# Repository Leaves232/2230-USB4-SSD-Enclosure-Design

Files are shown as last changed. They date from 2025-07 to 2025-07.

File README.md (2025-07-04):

## 2230 USB4 SSD Enclosure Design

The purpose of this project is to verify the feasibility of a 40Gbps SSD enclosure solution in limited volume. 

This design has gone through several iterations. The current open source design file includes support for active cooling and has considerable compatibility.

The finished product of the open-source file is shown in the picture. The design of the adaptive shell is still in the planning stage.

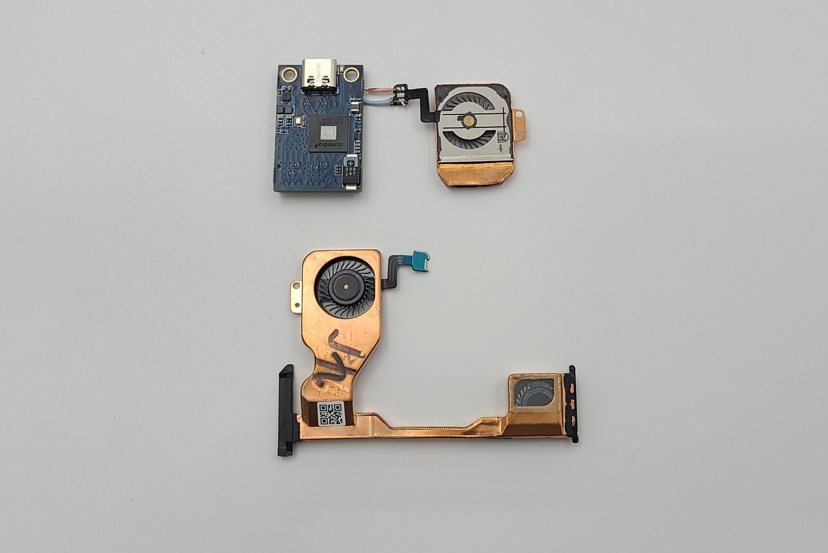
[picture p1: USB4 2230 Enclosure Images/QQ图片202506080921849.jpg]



### Function Availability

Speed tests using a P44 Pro 2T also confirmed that the design is fully functional

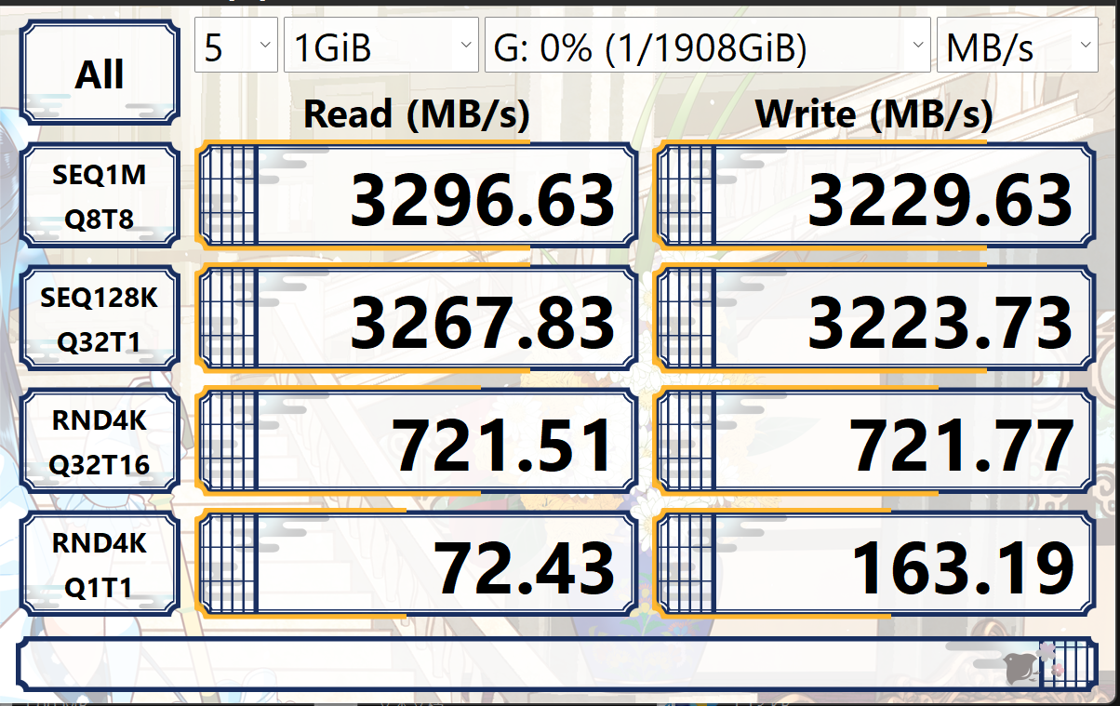
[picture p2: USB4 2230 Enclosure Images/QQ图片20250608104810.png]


This design has been checked to widely compatible with SSD.

It should be noted that due to limitation of the 3.3V Buck, it cannot meet the power consumption requirements of 4T SSDs. **Please use it with SSDs within 2T**.

## HOW TO USE FILES

**ASM2464PD DEMO Board B2 [Altium Designer]** folder contains the design source files developed using Altium Designer. You can make secondary modifications based on these files. The others are files used for finished product manufacturing.

### PCB Manufacturing

**Fabrication Files For DEMO Board B2** contains complete Gerber and drilling files for PCB production, which can be compressed and uploaded directly to board manufacturers such as JLC and Huaqiu for production. 

The PCB in Image Sets was made by Huaqiu PCB, and the stackup used was **04161H02-1080**. If you plan to produce the same PCB, please sent it directly to Huaqiu according to the corresponding parameters. 

If you plan to produce via other manufacturers, please emphasize to the production staff that the differential line impedance of the top and bottom layers should be controlled to about 85ohm according to the impedance requirements in the folder.

| 参数/Configuration | 下单参数/Parameter|
| --- | --- |
|板材类型/Board Material Type | FR-4 |
| 板子层数/Number of Layers | 4 |
| 板子厚度/Board Thickness | 1.6 |
| 最小线宽线距/Minimum Trace Width/Space | 3.5 / 3.5 mil |
| 最小过孔/Minimum Via Size | 0.20 mm |
| BGA | 无/None |
| 半孔/Castellated Hole | 无需/Not required |
| 包边/Edge Bonding / Board Edge Plating | 无需/Not required |
| 盲埋孔/Buried Via  | 无/None |
| 阻抗/Impedance Control  | 有/Require |
| 叠层结构/Layer Stack-up Structure | 04161H02-1080 |
| 焊盘喷镀/Surface Finish | 沉金(1u)/ENIG (1μm Au) |
| 外层铜厚/Outer Layer Copper Weight | 1oz |
| 内层铜厚/Inner Layer Copper Weight | 0.5oz |
| 阻焊颜色/Solder Mask Color | 蓝色/Blue |
| 字符颜色/Legend Color | 白色/White |
| 阻焊覆盖/Solder Mask Coverage  | 过孔盖油/Via Tent |
| 盘中孔/Via-in-Pad  | 无/None |
| 沉金厚度/Electroless Nickel Immersion Gold  | 1 μ″ |
| 板材品牌/Laminate Brand | 建滔 |
| TG值/Tg Value (Glass Transition Temperature) | TG150 |

### SMT Manufacturing

**Bill of Materials for B2 Sample.xlsx** could be used to prepare components for PCBA manufacturing.

**Pick Place for ASM2464PD - B2 Sample.csv** is the location coordinates of each component, which is used to provide parameters for the SMT placement machine.

 When purchasing materials on your own, Please pay attention to packaging, capacitor withstand voltage, and price issues, or refer to the material selection list I used at Huaqiu **PCBA Project - BOM Quotation for 2230 USB4 Enclosure**

Please refer to the picture for SMT finished product effect

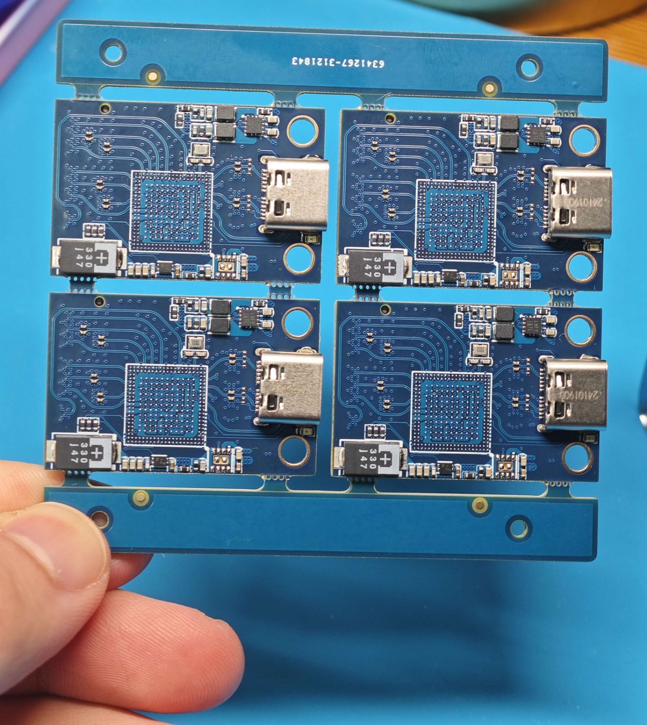
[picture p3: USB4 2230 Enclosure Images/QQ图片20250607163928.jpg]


### Firmware Write

It is recommended to connect the completed ASM2464PD board to the USB port of computer when you try to write the firmware.

Download **ASM2464PD_FW_250123_85_00_00.zip** and unzip it to a separate folder

Unzip **20231221_ASM246xMPTool_v1.0.4.1** and run **ASM246xMPTool.exe**

Please follow the prompts below

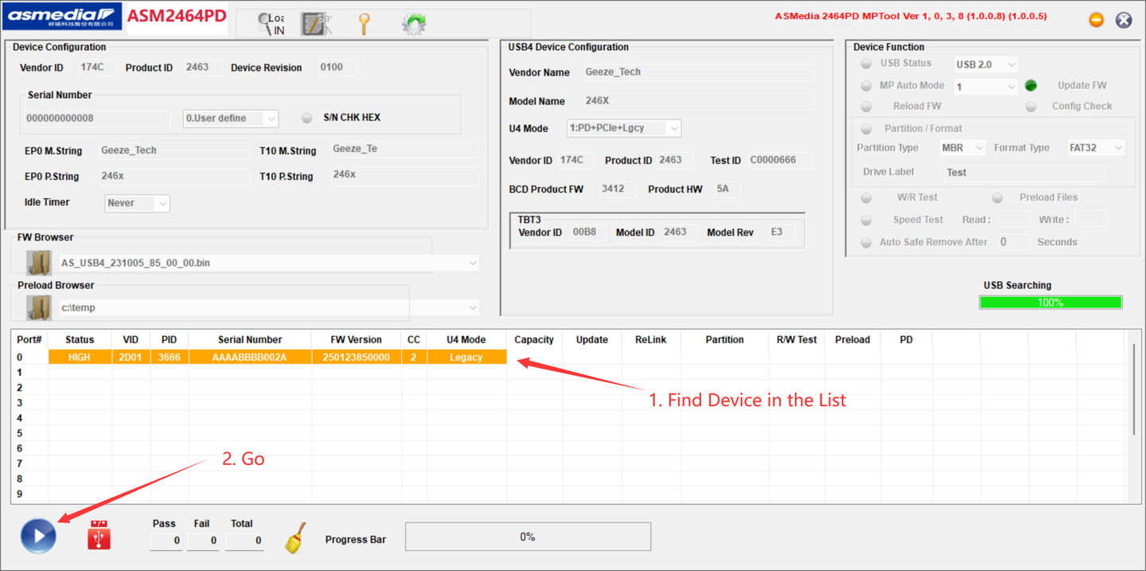
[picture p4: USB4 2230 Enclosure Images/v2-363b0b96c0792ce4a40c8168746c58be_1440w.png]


For other tips, please refer to the ASM2464PD_PDX mptool instructions in the folder

### Cooling Fan

Caution: ASM2464PD finished product will inevitably overheat and disconnect without heat dissipation.

The cooling fan in the demo is obtained by cutting the cooling module of Lenovo Legion Pro2.

You can connect it with flying wires, apply silicone grease and press it directly on the 2464 main controller.

### Congratulations, after completing the above steps you have a fully functional USB4 2230 SSD enclosure !

## License

The design is jointly completed by **@Leaves** and **@七上八下**. 

This project is open sourced under the MIT protocol.

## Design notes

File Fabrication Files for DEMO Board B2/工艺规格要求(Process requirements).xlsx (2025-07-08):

板材类型/Material Type | FR-4
板子层数/Layer Count | 4
板子厚度/Board Thickness | 1.6mm
外层铜厚/Outer Layer Copper Weight | 1oz
内层铜厚/Inner Layer Copper Weight | 1oz
阻抗/Impedance Control | 50/85
阻抗要求/Impedance Requirements
层 |  | 阻抗类型/Impedance type | 阻抗/Impedance | 线宽/Trace Width | 间距/Clearance
Layer | 1 | 差分/Differential Pair | 85Ohm | 4.36mil | 4mil
 |  | 单端/Single-ended | 50Ohm | 4.5mil | /
 | 2-3 | 差分/Differential Pair | 85Ohm | 3.69mil | 4mil
 |  | 单端/Single-ended | 50Ohm | 3.92mil | /
 | 4 | 差分/Differential Pair | 85Ohm | 4.36mil | 4mil
 |  | 单端/Single-ended | 50Ohm | 4.5mil | /

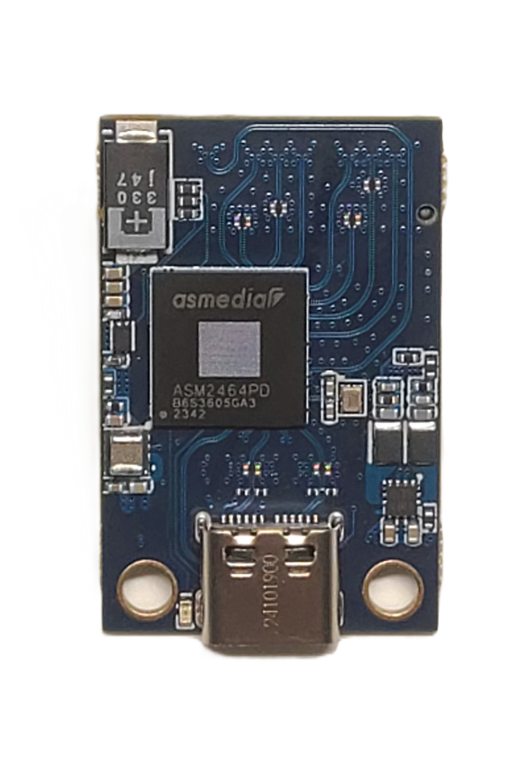
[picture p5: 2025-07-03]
USB4 2230 Enclosure Images/QQ图片20250607053230.png

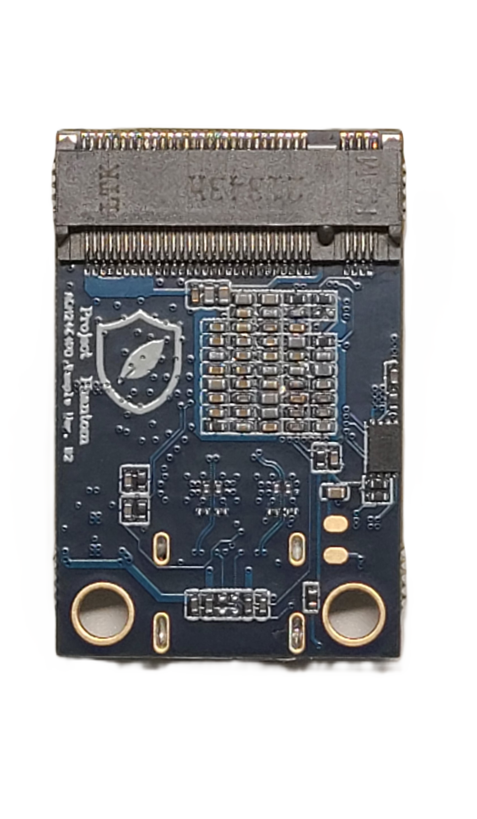
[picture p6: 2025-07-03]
USB4 2230 Enclosure Images/QQ图片20250607053236.png

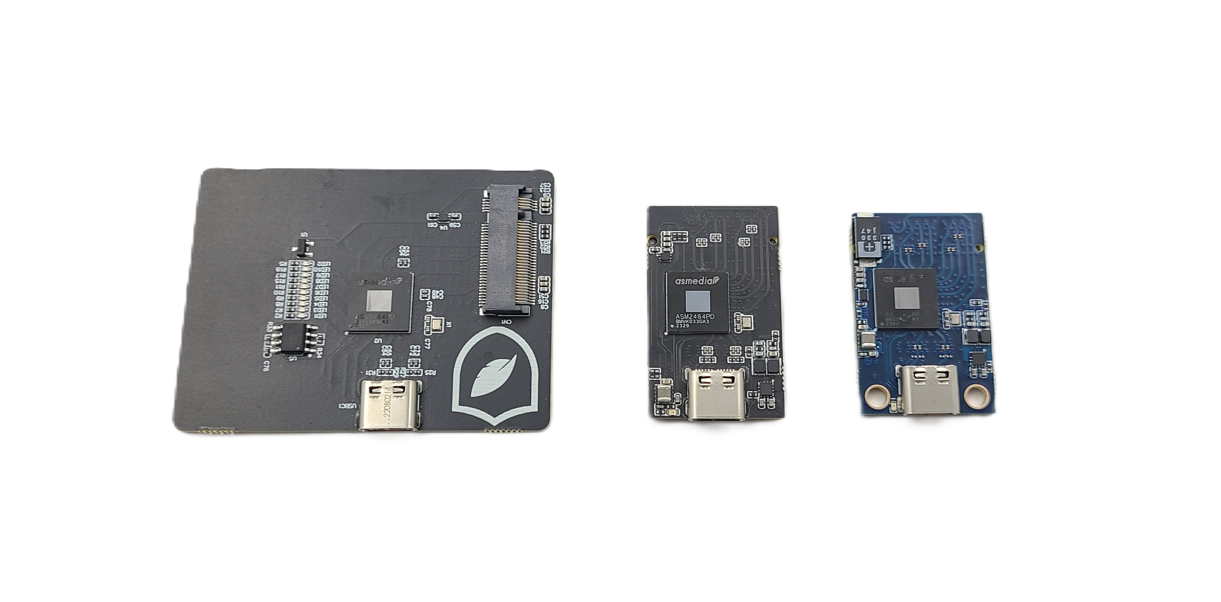
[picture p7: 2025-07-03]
USB4 2230 Enclosure Images/QQ图片2025060q8093125.jpg

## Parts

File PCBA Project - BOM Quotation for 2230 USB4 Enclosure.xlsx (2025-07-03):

PCBA Project - BOM Quotation
 |  |  |  |  |  | 65.71 |  |  | 报价有效期至：2025-05-12 06:30:00
 |  |  |  |  |  | “华秋商城”BOM匹配数据
序号/NO. | 型号/Part Number | 规格参数/Specifications | 封装//Package | 单机用量Usage per Unit | 位号/Reference Designator | 型号/Part Number | 描述/Description | 品牌/Manufacturer Brand | 含税单价(¥)/Unit Price (CNY, Tax incl.)
1 |  | 22uF | C0402 | 3 | C7, C102,C108 | GRM155R60J226ME11D | 贴片电容（MLCC） 0402 22µF ±20% 6.3V X5R | Samsung | 0.22275
2 |  | 10uF | C0402 | 15 | C4, C8, C13, C16, C20, C23, C40, C43, C46, C51, C57, C103, C104, C109,C100 | CL05A106MQ5NUNC | 贴片电容（MLCC） 0402 10µF ±20% 6.3V X5R | Samsung | 0.02281
3 |  | 2.2uf | C0402 | 26 | C1, C3, C6, C10, C12, C15, C17, C19, C22, C24, C26, C28, C29, C30, C32, C33, C35, C36, C37, C38, C39, C41, C42, C44, C45, C47 | CL05A225KP5NSNC | 贴片电容（MLCC） 0402 2.2µF ±10% 10V X5R | Samsung | 0.01346
4 |  | 100nF | C0402 | 16 | C2, C5, C9, C11, C14, C18, C21, C25, C27, C31, C61, C66, C67, C70, C71, C76 | 0402F104M500NT | 贴片电容（MLCC） 0402 100nF ±20% 50V Y5V | FH | 0.00481
5 |  | 1uF | C0402 | 1 | C34 | 0402X105K6R3NT | 贴片电容（MLCC） 0402 1µF ±10% 6.3V X5R | FH | 0.00766
6 |  | 220nF | C0201 | 12 | C48, C49, C50, C52, C53, C54, C55, C56, C64, C65, C74, C75 | GRM033R60J224ME15D | 贴片电容（MLCC） 0201 220nF ±20% 6.3V X5R | Murata | 0.00917
7 |  | 20pF | C0402 | 1 | C59 | CC0402JRNPO9BN200 | 贴片电容（MLCC） 0402 20pF ±5% 50V C0G(NP0) | Yageo | 0.00456
8 |  | 330nF | C0201 | 4 | C62, C63, C72, C73 | GRM033R60J334ME90D | 贴片电容（MLCC） 0201 330nF ±20% 6.3V X5R | Murata | 0.05114
9 |  | 220pF | C0402 | 2 | C68, C69 | 0402B221K500NT | 贴片电容（MLCC） 0402 220pF ±10% 50V X7R | FH | 0.00433
10 |  | 30pF | C0402 | 2 | C77, C78 | 0402CG300J500NT | 贴片电容（MLCC） 0402 30pF ±5% 50V C0G(NP0) | FH | 0.00454
11 |  | 4.7pf | C0402 | 1 | C101 | 0402CG4R7B500NT | 贴片电容（MLCC） 0402 4.7pF ±0.1pF 50V | FH | 0.00744
12 |  | 6.8pf | C0402 | 1 | C105 | 0402CG6R8C500NT | 贴片电容（MLCC） 0402 6.8pF ±0.25pF 50V C0G(NP0) | FH | 0.00420
13 |  | 33u | C0402 | 1 | C106 | GRM155R60J226ME11D | GRM158R61A226ME15D | Murata | 0.67700
14 |  | 3.3nf | C0402 | 1 | C107 | 0402B332K500NT | 贴片电容（MLCC） 0402 3.3nF ±10% 50V X7R | FH | 0.00382
15 |  | 330uF | CAP-SMD_L7.3-W4.3-R-RD | 1 | CE1 | 6TPE330MAP | 钽聚合物电容器 D7343-18 330µF ±20% 6.3V 7.30 x 4.30mm 25mΩ | Panasonic | 2.37008
16 | M.2-MKEY CONNECTOR | M.2-MKEY CONNECTOR | CONN-SMD_APCI0113-P001A | 1 | CN1 | NASM0-S6701-TPH4 | M.2 M KEY H3.0 | ARGOSY | 1.41750
17 |  | HDR1x1 | Header | 2 | J17, J18 | NC
18 |  | 1uh | IND-SMD_L2.0-W1.6-B | 2 | L5, L6 | FTC201610S1R0MBCA | 2.0*1.6*1.0 (201610) 电感值:1.0µH 精度:±20% 饱和电流（isat）：4.6A 温升电流（irms）：4.5A 直流电阻(DCR)：35mΩ | cjiang | 0.19611
19 | 19-217/R6C-AL1M2VY/3T | 19-217/R6C-AL1M2VY/3T | LED0402-RD | 1 | LED1 | 19-217/R6C-AL1M2VY/6T | 发光二极管/LED 0603 红灯 正贴 | Everlight | 0.07979
20 |  | 4.7K 1% | R0402 | 5 | R1, R2, R3, R33, R34 | 0402WGF4701TCE | 贴片电阻 0402 4.7KΩ ±1% 1/16W ±100ppm/℃ | Uniohm | 0.00219
21 |  | 12.1K 1% | R0402 | 1 | R4 | 0402WGF1212TCE | 贴片电阻 0402 12.1KΩ ±1% 1/16W ±100ppm/℃ | Uniohm | 0.00212
22 |  | 100K 1% | R0402 | 3 | R6, R104, R106 | 0402WGF1003TCE | 贴片电阻 0402 100KΩ ±1% 1/16W ±100ppm/℃ | Uniohm | 0.00200
23 |  | 0 | R0402 | 2 | R12, R13 | 0402WGF0000TCE | 贴片电阻 0402 0Ω ±1% 1/16W | Uniohm | 0.00198
24 |  | 2M /NC | R0402 | 2 | R14, R16 | NC
25 |  | 100K /NC | R0402 | 1 | R19 | NC
26 |  | 1K 1% | R0402 | 1 | R20 | 0402WGF1001TCE | 贴片电阻 0402 1KΩ ±1% 1/16W ±100ppm/℃ | Uniohm | 0.00222
27 |  | 10K 1% | R0402 | 5 | R21, R22, R23, R103, R110 | 0402WGF1002TCE | 贴片电阻 0402 10KΩ ±1% 1/16W ±100ppm/℃ | Uniohm | 0.00216
28 |  | 220K 1% | R0201 | 8 | R24, R25, R26, R27, R28, R29, R30, R31 | 0201WMF2203TEE | 贴片电阻 0201 220KΩ ±1% 1/20W ±200ppm/℃ | Uniohm | 0.00446
29 |  | 140K 1% | R0402 | 1 | R105 | RC0402FR-07140KL | 贴片电阻 0402 140KΩ ±1% 1/16W ±100ppm/℃ | Yageo | 0.00279
30 |  | 261K 1% | R0402 | 1 | R107 | 0402WGF2613TCE | 贴片电阻 0402 261KΩ ±1% 1/16W ±100ppm/℃ | UniOhm | 0.00216
31 |  | 475K 1% | R0402 | 1 | R108 | RC0402FR-07475KL | 贴片电阻 0402 475KΩ ±1% 1/16W ±100ppm/℃ | Yageo | 0.00446
32 |  | 150K 1% | R0402 | 1 | R109 | 0402WGF1503TCE | 贴片电阻 0402 150KΩ ±1% 1/16W ±100ppm/℃ | Uniohm | 0.00213
33 | tpc60t_68 | tpc60t_68 | tpc60t_68 | 2 | TP1, TP2
34 | LTC3315AEV#TRPBF | LTC3315AEV#TRPBF | LQFN-12_L2.0-W2.0-P0.50-TL-EP0.7 | 1 | U01 | LTC3315AEV#TRPBF | IC REG BUCK 6A STEP-DOWN | ADI | 16.64280
35 | ASM2464PD | ASM2464PD | BGA273C46P21X21_1000X1000X98 | 1 | U2
36 | TPS82130SILR | TPS82130SILR | USIP-8_L3.0-W2.8-P0.65-TL-EP | 1 | U02 | TPS82130SILR | 非隔离 PoL 模块 直流转换器 1 输出 0.9 ~ 5V 3A 3V - 17V 输入 μSIP8_3X2.8MM | TI | 22.94600
37 | SIP32408DNP-T1-GE4 | SIP32408DNP-T1-GE4 | SIP32408DNP-T1-GE4 | 1 | U4 | SIP32408DNP-T1-GE4 | IC PWR SWITCH N-CHAN 1:1 4TDFN | Vishay | 4.50360
38 | ZD25WQ16CEIGR | ZD25WQ16CEIGR | USON-8_L3.0-W2.0-P0.50-BL-EP | 1 | U31 | ZD25WQ16CEIGR |  | Zetta(澜智) | 1.02600
39 | 105450-0101 | 105450-0101 | USB-C-SMD_TYPE-C-USB-18 | 1 | USBC1 | 105450-0101 |  | Molex | 6.32500
40 |  | 25MHz | CRYSTAL-SMD_4P-L1.6-W1.2-BL | 1 | X1 | X322525MSB4SI | 无源晶振 25MHz 50Ω 20pF ±10ppm -40℃~+85℃ SMD3225_4P | YXC | 0.29520

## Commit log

2025-06-11 Altium raw files for 2230 ASM2464PD Board
    Prototype design completed with Altium Designer, which can be modified, previewed, etc. in Altium software
    [ASM2464PD.PcbLib, ASM2464PD.PrjPcb, ASM2464PD.SchDoc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]
2025-06-11 B2 Sample Fabrication Documents
    Files directly for B2 sample PCB manufacture
    [ASM2464PD - B2 Sample.GBL, ASM2464PD - B2 Sample.GBO, ASM2464PD - B2 Sample.GBP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]
2025-06-11 Bill of Materials For 2230 USB4 SSD Enclosure
    Contains a list of components required to manufacture a single B2 sample
    [Bill of Materials for B2 Sample.xlsx]
2025-06-11 Pick Place for components of B2 Sample
    Fabrication File for SMT Stage
    [Pick Place for ASM2464PD - B2 Sample.csv]
2025-07-03 BOM Quotation for 2230 USB4 Enclosure
    [PCBA Project - BOM Quotation for 2230 USB4 Enclosure.xlsx]
2025-07-03 Images for 2230 USB4 Enclosure
2025-07-03 README.md
    Demo Board Production Guide
2025-07-08 update the configuration
    [工艺规格要求(Process requirements).xlsx]
2025-07-08 update configuration
    [工艺规格要求(Process requirements).xlsx]
